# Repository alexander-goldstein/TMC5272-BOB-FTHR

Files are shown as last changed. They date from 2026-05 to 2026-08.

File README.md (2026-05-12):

# TMC5272-BOB-FTHR

An adapter board for connecting Adafruit Feather-format MCU boards to the TMC5272 breakout board (BOB) for prototyping applications.

**Trinamic / Analog Devices, Inc.**

## Overview

This adapter board provides a simple platform for connecting any Adafruit Feather (FTHR) form factor microcontroller to a TMC5272-BOB. The board breaks out connections including SPI, power, and control signals to facilitate rapid prototyping and evaluation of the TMC5272 stepper motor driver.

This project was designed with KiCad 10.

## Features

- Compatible with Adafruit Feather form factor MCU boards.
- Dual-row headers: Inner column accepts female headers for board insertion, outer column (optional) for male pins to probe signals or attach jumper wires.
- Flexible signal routing: CS, DIAG0, and DIAG1 are jumper-configurable to connect to any desired MCU pin.
- Test points for easy debugging.

## Board Layout

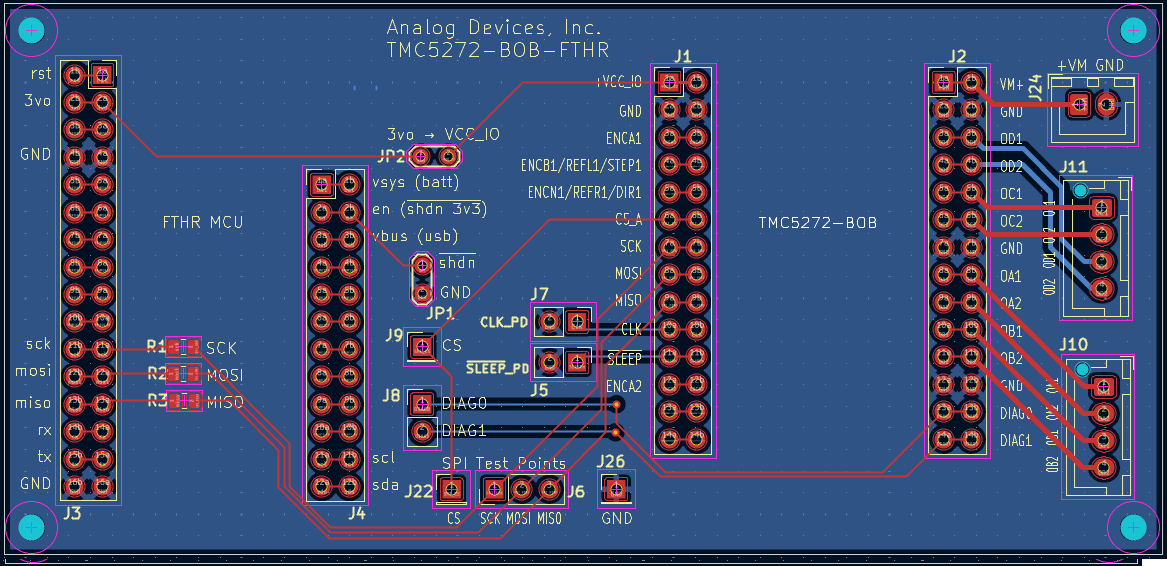
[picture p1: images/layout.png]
Board Layout


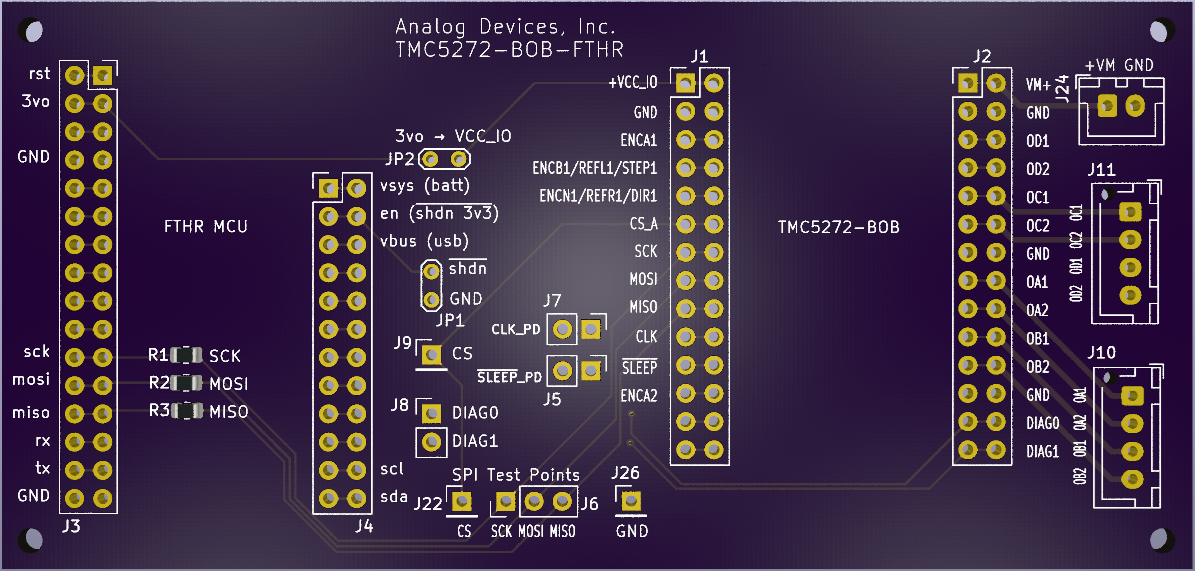
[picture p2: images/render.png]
3D Render


## Fabrication

Gerber files are available in the `gerber/` directory. The ZIP file in that folder can be uploaded directly to [OSH Park](https://oshpark.com/) for fabrication.

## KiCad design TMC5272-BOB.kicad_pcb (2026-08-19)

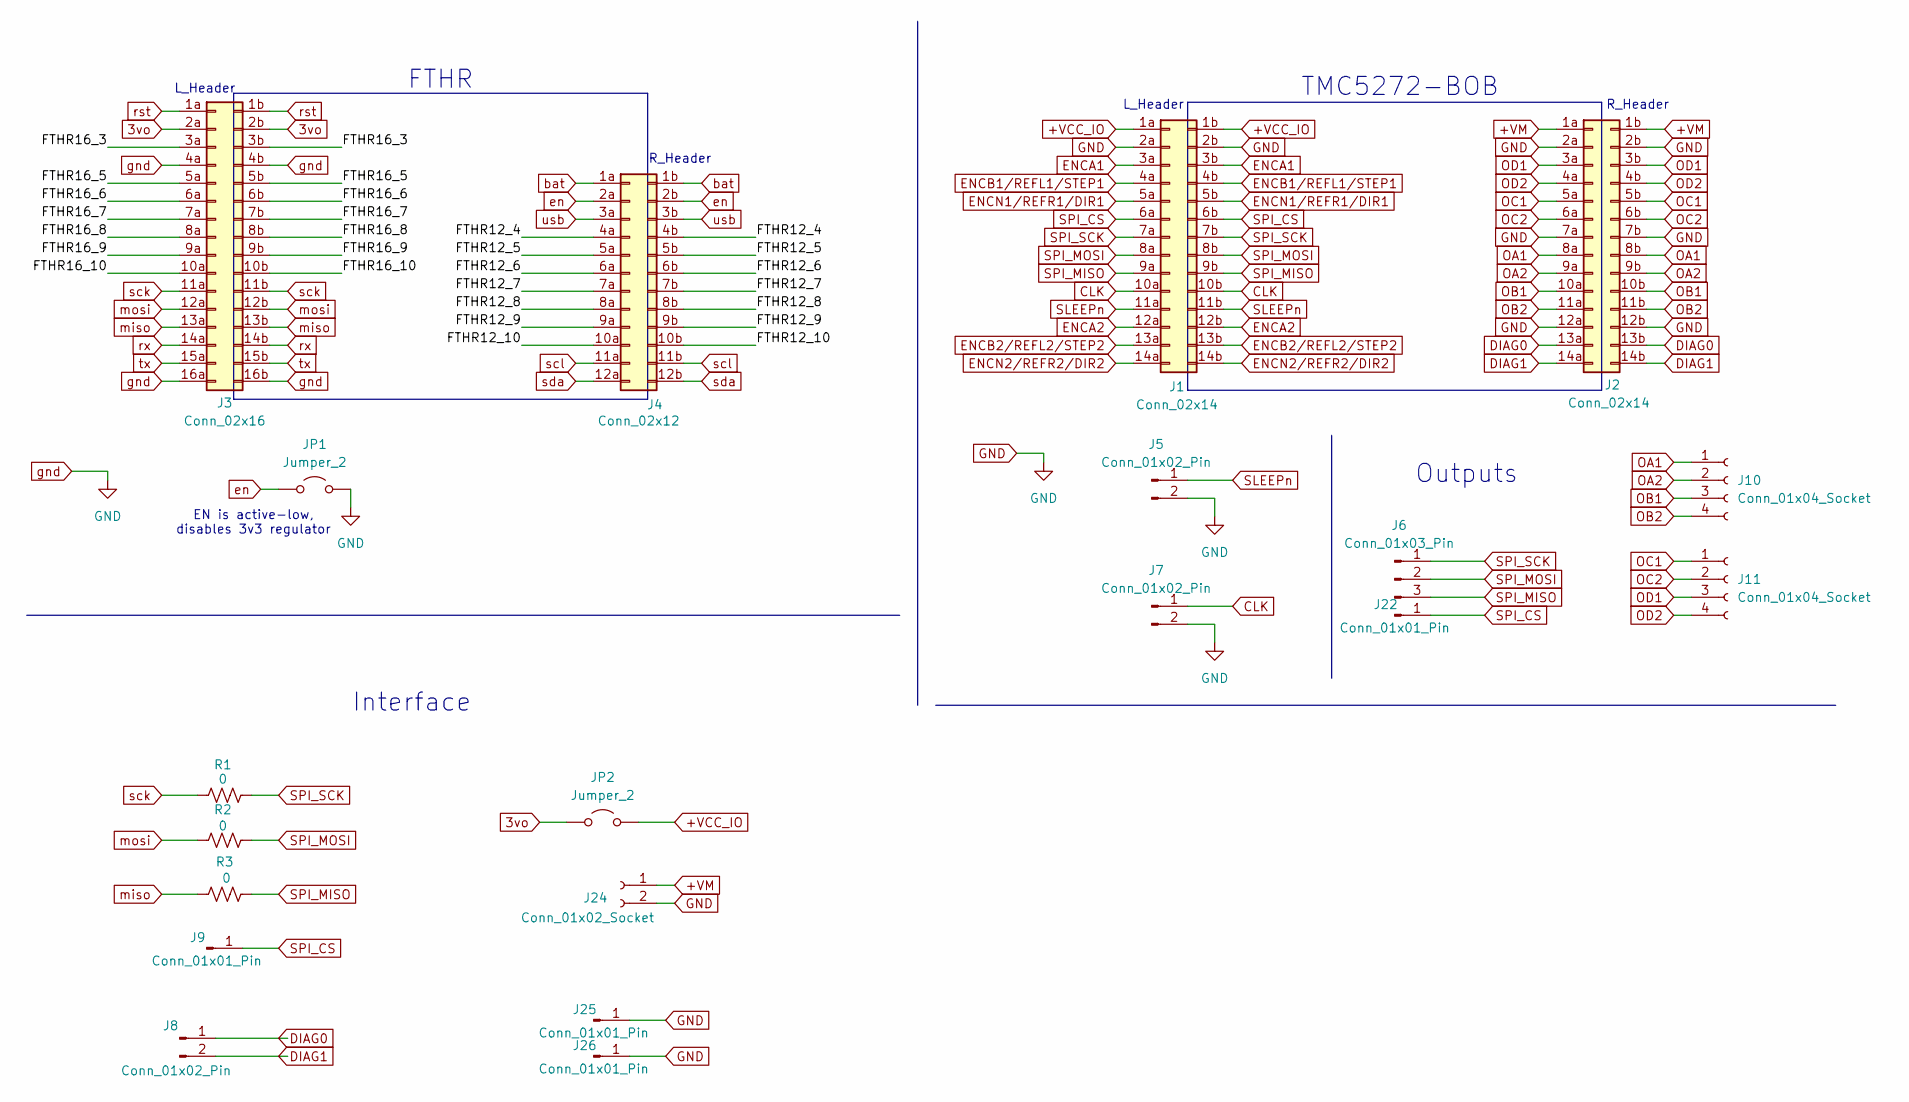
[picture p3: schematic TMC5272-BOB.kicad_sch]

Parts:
J1, J2: Conn_02x14; PinHeader_2x14_P2.54mm_Vertical
J3: Conn_02x16; PinSocket_2x16_P2.54mm_Vertical
J4: Conn_02x12; PinHeader_2x12_P2.54mm_Vertical
J5, J7, J8: Conn_01x02_Pin; PinHeader_1x02_P2.54mm_Vertical
J6: Conn_01x03_Pin; PinHeader_1x03_P2.54mm_Vertical
J9, J22, J25, J26: Conn_01x01_Pin; PinHeader_1x01_P2.54mm_Vertical
J10, J11: Conn_01x04_Socket; JST_XH_B4B-XH-AM_1x04_P2.50mm_Vertical
J24: Conn_01x02_Socket; JST_XH_B2B-XH-A_1x02_P2.50mm_Vertical
JP1, JP2: Jumper_2; TestPoint_2Pads_Pitch2.54mm_Drill0.8mm
R1, R2, R3: 0; R_0805_2012Metric

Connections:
3vo: J3.2a, J3.2b, JP2.1 (A)
+VCC_IO: J1.1a, J1.1b, JP2.2 (B)
+VM: J2.1a, J2.1b, J24.1
/FTHR12_4: J4.4a, J4.4b
/FTHR12_5: J4.5a, J4.5b
/FTHR12_6: J4.6a, J4.6b
/FTHR12_7: J4.7a, J4.7b
/FTHR12_8: J4.8a, J4.8b
/FTHR12_9: J4.9a, J4.9b
/FTHR12_10: J4.10a, J4.10b
/FTHR16_3: J3.3a, J3.3b
/FTHR16_5: J3.5a, J3.5b
/FTHR16_6: J3.6a, J3.6b
/FTHR16_7: J3.7a, J3.7b
/FTHR16_8: J3.8a, J3.8b
/FTHR16_9: J3.9a, J3.9b
/FTHR16_10: J3.10a, J3.10b
CLK: J1.10a, J1.10b, J7.1
DIAG0: J2.13a, J2.13b, J8.1
DIAG1: J2.14a, J2.14b, J8.2
ENCA1: J1.3a, J1.3b
ENCA2: J1.12a, J1.12b
ENCB1/REFL1/STEP1: J1.4a, J1.4b
ENCB2/REFL2/STEP2: J1.13a, J1.13b
ENCN1/REFR1/DIR1: J1.5a, J1.5b
ENCN2/REFR2/DIR2: J1.14a, J1.14b
GND: J1.2a, J1.2b, J2.2a, J2.2b, J2.7a, J2.7b, J2.12a, J2.12b, J3.4a, J3.4b, J3.16a, J3.16b, J5.2, J7.2, J24.2, J25.1, J26.1 (Pin_1_1), JP1.2 (B)
OA1: J2.8a, J2.8b, J10.1
OA2: J2.9a, J2.9b, J10.2
OB1: J2.10a, J2.10b, J10.3
OB2: J2.11a, J2.11b, J10.4
OC1: J2.5a, J2.5b, J11.1
OC2: J2.6a, J2.6b, J11.2
OD1: J2.3a, J2.3b, J11.3
OD2: J2.4a, J2.4b, J11.4
SLEEPn: J1.11a, J1.11b, J5.1
SPI_CS: J1.6a, J1.6b, J9.1 (Pin_1_1), J22.1 (Pin_1_1)
SPI_MISO: J1.9a, J1.9b, J6.3, R3.2
SPI_MOSI: J1.8a, J1.8b, J6.2, R2.2
SPI_SCK: J1.7a, J1.7b, J6.1, R1.2
bat: J4.1a, J4.1b
en: J4.2a, J4.2b, JP1.1 (A)
miso: J3.13a, J3.13b, R3.1
mosi: J3.12a, J3.12b, R2.1
rst: J3.1a, J3.1b
rx: J3.14a, J3.14b
sck: J3.11a, J3.11b, R1.1
scl: J4.11a, J4.11b
sda: J4.12a, J4.12b
tx: J3.15a, J3.15b
usb: J4.3a, J4.3b

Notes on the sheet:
L_Header
FTHR
Interface
R_Header
EN is active-low, disables 3v3 regulator
Outputs
TMC5272-BOB

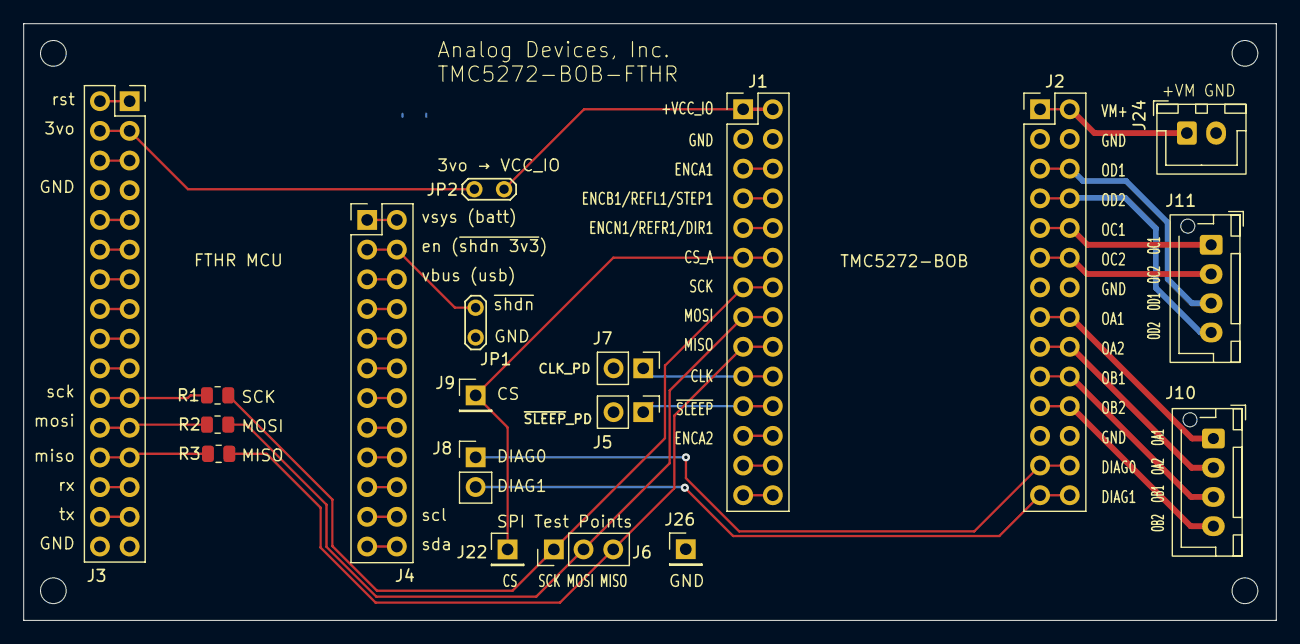
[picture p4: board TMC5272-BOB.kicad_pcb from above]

Board: 2 copper layers, 107.2 x 51.1 mm, 19 parts (0 on the bottom side), 51 nets.

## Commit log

2026-05-12 Initial commit.
    [TMC5272-BOB-B_Cu.gbr, TMC5272-BOB-B_Mask.gbr, TMC5272-BOB-B_Paste.gbr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]
2026-08-19 Fix BOB pin spacing.
    [TMC5272-BOB-B_Cu.gbr, TMC5272-BOB-B_Mask.gbr, TMC5272-BOB-B_Paste.gbr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]
